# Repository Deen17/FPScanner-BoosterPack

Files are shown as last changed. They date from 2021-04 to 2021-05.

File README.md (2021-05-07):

# CCS Code for the FPScanner
For use with a GT-521FXX Fingerprint Scanner. 

This project contains library code for the fingerprint scanner, compatible with TI LaunchPad devices. To follow along with the entire design of the project, check out https://www.hackster.io/adilr3/fpscanner-boosterpack-739ad2.

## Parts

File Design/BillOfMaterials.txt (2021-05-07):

Quantity	Value	Package	Order code	Manufacturer	Manuf. Code	Availability	Price (from)	Description
-------
2   2x10 HEADERS 2x10	SAM15296-ND SAMTEC	SSW-110-23-F-D I found https://www.digikey.com/en/products/detail/SSW-110-23-F-D/SAM15296-ND/6692909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, which shows these 2x10 headers are in stock. Should only need 2 of these)
-------

Quantity	Value	Package	Order code	Manufacturer	Manuf. Code	Availability	Price (from)	Description
2	10k	R0805	53W8524	PANASONIC	ERJ6GEYJ103V	50390	0.021	PANASONIC - ERJ6GEYJ103V - Surface Mount Chip Resistor, Thick Film, AEC-Q200 ERJ Series, 10 kohm, 125 mW, 5%, 150 V RoHS Compliant: Yes
1	20k	R0805	65J1661	VISHAY	CRCW080520K0FKEB	6392	0.014	VISHAY - CRCW080520K0FKEB - SMD Chip Resistor, 20 kohm, ± 1%, 125 mW, 0805 [2012 Metric], Thick Film, General Purpose
2		1X04_1MM_RA	87R0314	JST (JAPAN SOLDERLESS TERMINALS)	SM04B-SRSS-TB(LF)(SN)	8511	0.347	JST (JAPAN SOLDERLESS TERMINALS) - SM04B-SRSS-TB(LF)(SN) - Pin Header, Wire-to-Board, 1 mm, 1 Rows, 4 Contacts, Surface Mount, SH Series
1	M3 Screws PRT-13227	Sparkfun	https://www.sparkfun.com/products/13227 
4	M3 Nuts

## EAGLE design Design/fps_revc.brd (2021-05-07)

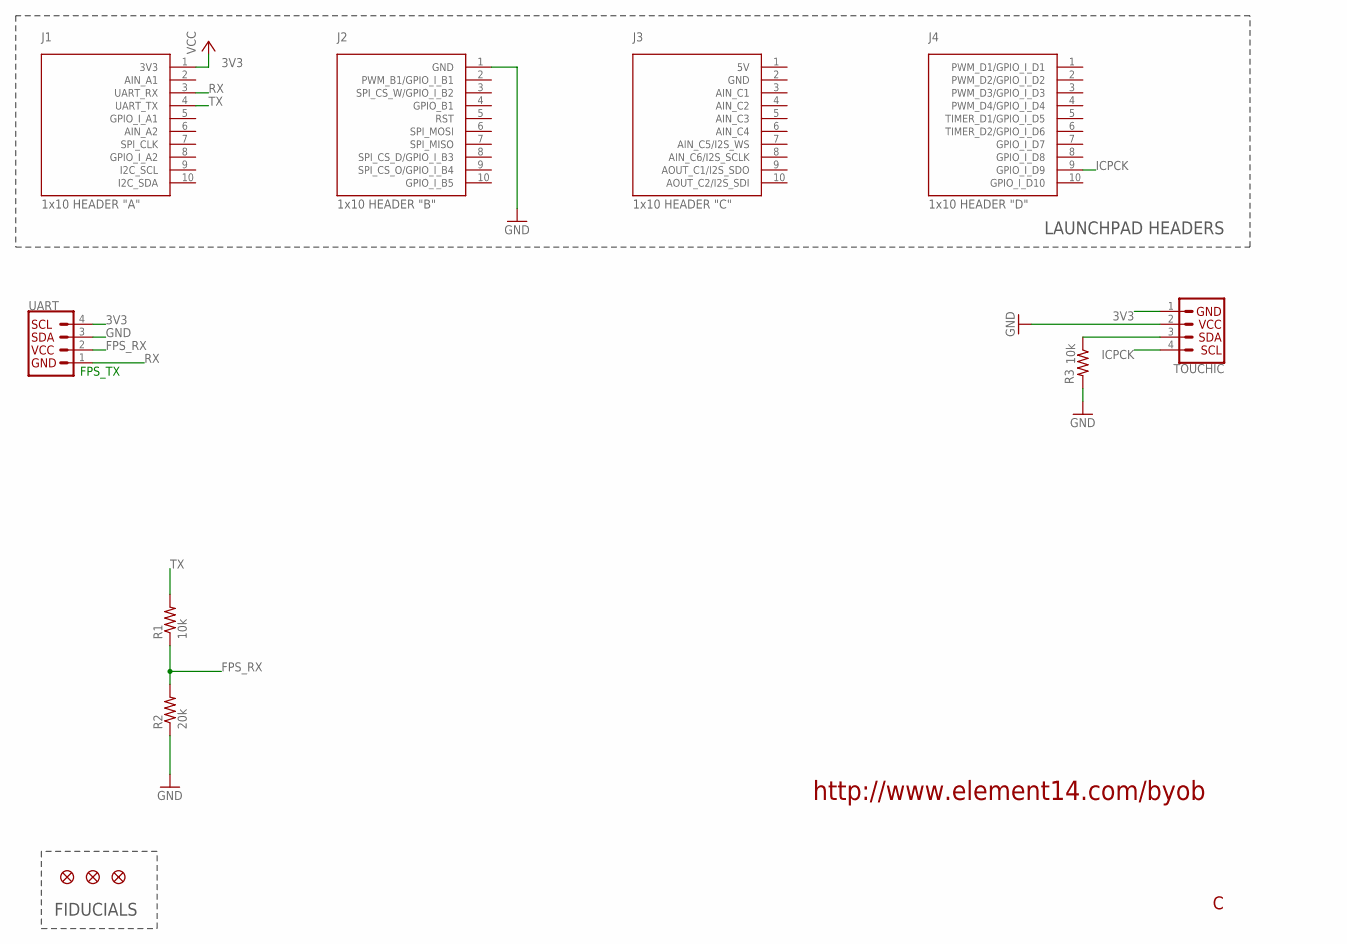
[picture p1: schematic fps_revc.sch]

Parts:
FID1, FID2, FID3: FIDUCIAL; FIDUCIAL_L10
J1: 1x10 HEADER "A"; 1X10; MPN SSW-110-23-F-D
J2: 1x10 HEADER "B"; 1X10; MPN SSW-110-23-F-D
J3: 1x10 HEADER "C"; 1X10
J4: 1x10 HEADER "D"; 1X10
R1, R3: 10k; R0805; MPN ERJ6GEYJ103V
R2: 20k; R0805; MPN CRCW080520K0FKEB
TOUCHIC: QWIIC_CONNECTORJS-1MM; 1X04_1MM_RA; MPN SM04B-SRSS-TB(LF)(SN)
UART: QWIIC_CONNECTORJS-1MM; 1X04_1MM_RA; MPN SM04B-SRSS-TB(LF)(SN)

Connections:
3V3: J1.1 (3V3), TOUCHIC.1 (GND), UART.4 (SCL)
FPS_RX: R1.1, R2.2, UART.2 (VCC)
GND: J2.1 (GND), R2.1, R3.2, TOUCHIC.2 (VCC), UART.3 (SDA)
ICPCK: J4.9 (GPIO_I_D9), TOUCHIC.4 (SCL)
unnamed: R3.1, TOUCHIC.3 (SDA)
RX: J1.3 (UART_RX), UART.1 (GND)
TX: J1.4 (UART_TX), R1.2

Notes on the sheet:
LAUNCHPAD HEADERS
FIDUCIALS
http://www.element14.com/byob
FPS_TX

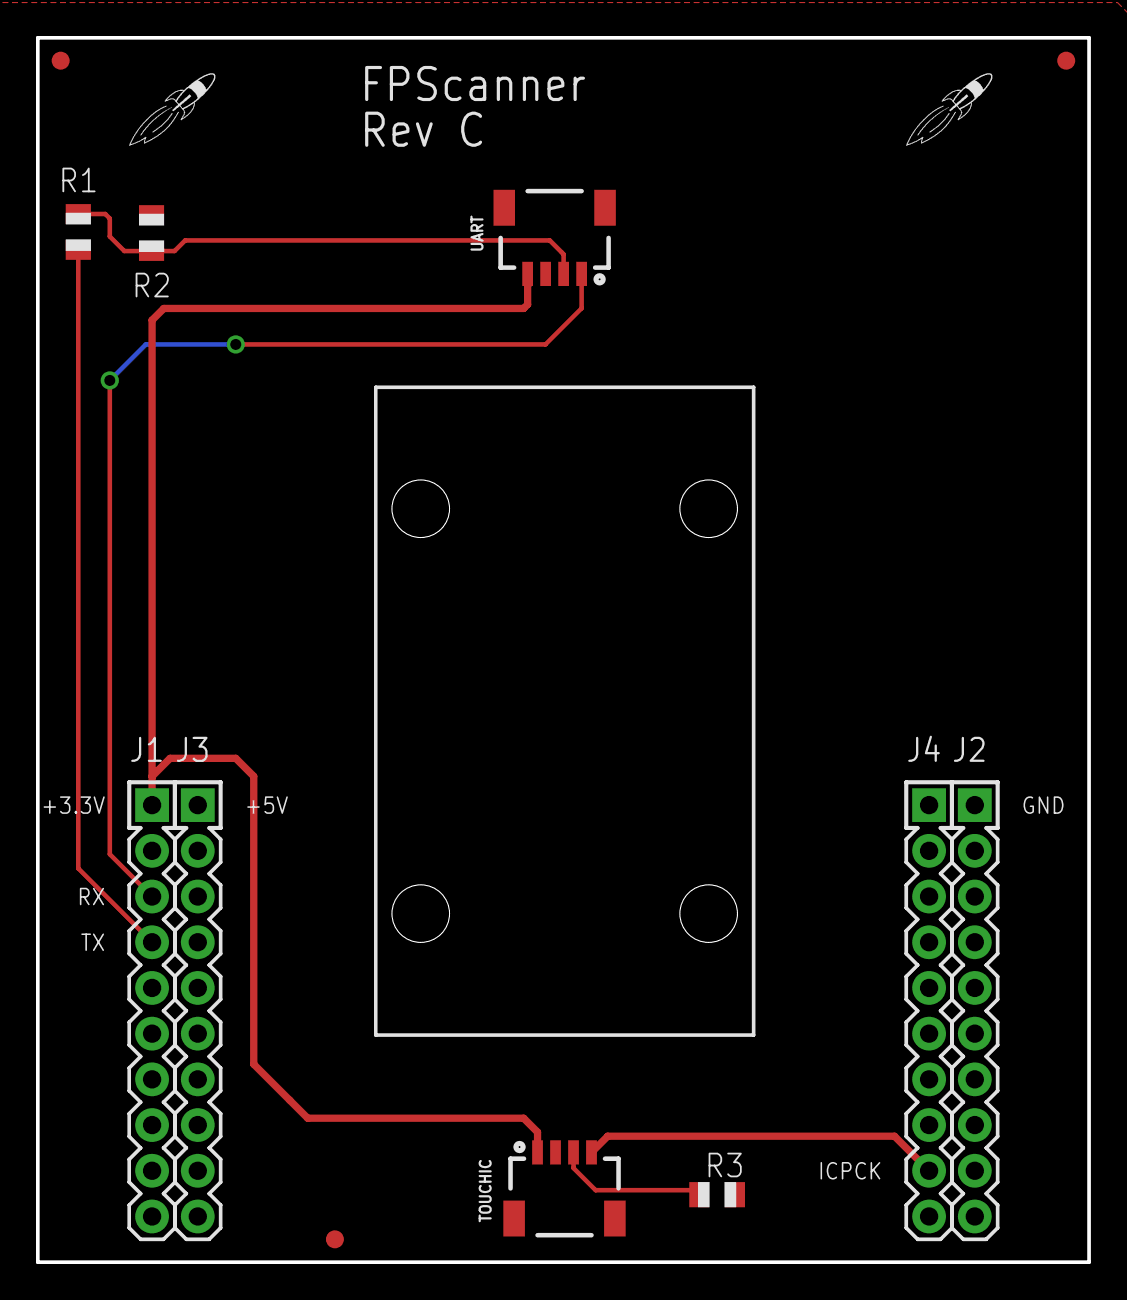
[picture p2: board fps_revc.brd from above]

Board: 2 copper layers, 58.4 x 68.0 mm, 14 parts (0 on the bottom side), 7 nets.

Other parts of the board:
U$1, U$2: LOGO-ROCKET

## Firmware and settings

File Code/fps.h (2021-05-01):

///
//
// 

#ifndef FPS_HEADER
#define FPS_HEADER

#ifndef TI_UART
#define TI_UART
#include <ti/drivers/UART.h>
#endif

#ifndef TI_DRIVERS_CONFIG
#define TI_DRIVERS_CONFIG
#include "ti_drivers_config.h"
#endif

#ifndef TI_GPIO
#define TI_GPIO
#include <ti/drivers/GPIO.h>
#endif

#define COMMAND_PACKET_SIZE 12
#define RESPONSE_PACKET_SIZE 12

typedef unsigned char byte;
typedef unsigned short word;
typedef unsigned long dword;

static byte command_start_code1 = 0x55;
static byte command_start_code2 = 0xaa;
static byte data_start_code1 = 0x5a;
static byte data_start_code2 = 0xa5;
static byte device_id1 = 0x01; // lsB; together, deviceID is 0x0001. the fingerprintscanner is little endian
static byte device_id2 = 0x00; // msB

// Command Codes
enum Command_Code
{
    OPEN = 0x01,
    CLOSE = 0x02,
    USB_INTERNAL_CHECK = 0X03,
    CHANGE_BAUDRATE = 0X04,
    CMOS_LED = 0X12,
    GET_ENROLL_COUNT = 0X20,
    CHECK_ENROLLED = 0X21,
    ENROLL_START = 0X22,
    ENROLL1 = 0X23,
    ENROLL2 = 0X24,
    ENROLL3 = 0X25,
    IS_PRESS_FINGER = 0X26,
    DELETE_ID = 0X40,
    DELETE_ALL = 0X41,
    VERIFY = 0X50,
    IDENTIFY = 0X51,
    VERIFY_TEMPLATE = 0X52,
    IDENTIFY_TEMPLATE = 0X53,
    CAPTURE_FINGER = 0X60,
    MAKE_TEMPLATE = 0X61,
    GET_IMAGE = 0X62,
    GET_RAW_IMAGE = 0X63,
    GET_TEMPLATE = 0X70,
    SET_TEMPLATE = 0X71,
    GET_DATABASE_START = 0X72,
    GET_DATABASE_END = 0X73,
    SET_SECURITY_LEVEL = 0XF0,
    GET_SECURITY_LEVEL = 0XF1,
    IDENTIFY_TEMPLATE2 = 0XF4,
    ENTER_STANDBY_MODE = 0XF9,
    ACK = 0X30,
    NACK = 0X31
} Command;

enum ERROR_CODES
{
    NACK_TIMEOUT = 0X1001,
    NACK_INVALID_BAUDRATE = 0X1002,
    NACK_INVALID_POS = 0X1003,
    NACK_IS_NOT_USED = 0X1004,
    NACK_IS_ALREADY_USED = 0X1005,
    NACK_COMM_ERR = 0X1006,
    NACK_VERIFY_FAILED = 0X1007,
    NACK_IDENTIFY_FAILED = 0X1008,
    NACK_DB_IS_FULL = 0X1009,
    NACK_DB_IS_EMPTY = 0X100A,
    NACK_TURN_ERR = 0X100B,
    NACK_BAD_FINGER = 0X100C,
    NACK_ENROLL_FAILED = 0X100D,
    NACK_IS_NOT_SUPPORTED = 0X100E,
    NACK_DEV_ERR = 0X100F,
    NACK_CAPTURE_CANCELED = 0X1010,
    NACK_INVALID_PARAM = 0X1011,
    NACK_FINGER_IS_NOT_PRESSED = 0X1012,
    INVALID = 0XFFFF
} Error_Code;

// // Response Codes
// enum Response_Code {
//     ACK  = 0x30,
//     NACK = 0x31
// } Response;

// Packet Structures

// Command Packet
typedef struct CMD_PKT
{
    dword parameter;
    word command;
} CommandPacket;

CommandPacket new_command_packet(word command, dword parameter);
word cmd_checksum(CommandPacket *self);
CommandPacket open_cmd(dword parameter);
CommandPacket close_cmd();
CommandPacket check_usb_cmd();
CommandPacket led_cmd(dword parameter);
CommandPacket led_on_cmd();
CommandPacket led_off_cmd();
CommandPacket change_baud_cmd(dword parameter);
CommandPacket get_enroll_count_cmd();
CommandPacket check_enrollment_cmd(dword id);
CommandPacket start_enrollment_cmd(dword id);
CommandPacket enroll1_cmd();
CommandPacket enroll2_cmd();
CommandPacket enroll3_cmd();
CommandPacket check_finger_pressed_cmd();
CommandPacket delete_one_fingerprint_cmd(dword id);
CommandPacket delete_all_cmd();
CommandPacket verify_cmd(dword id);
CommandPacket identify_cmd();
CommandPacket capture_finger_cmd(dword quality);
CommandPacket get_fingerprint_img_cmd();
CommandPacket set_security_level_cmd(dword level);
CommandPacket get_security_level_cmd();
CommandPacket enter_standby_cmd();


byte* command_packet_payload(CommandPacket *self);


// Response Packet

typedef struct RES_PKT
{
    word start_code;
    word device_id;
    dword parameter;
    word response;
    word checksum;
} ResponsePacket;

ResponsePacket new_response_packet(byte* buf);
int isAck(ResponsePacket *res);
int expected_checksum(dword parameter, word response);

// Data Packets

//typedef struct DATA_PACKET
//{
//    byte start1;
//    byte start2;
//    word dev_id;
//    byte *data;
//    word checksum;
//    unsigned int size;
//} DataPacket;

//DataPacket data_packet(byte *buf, int size);
//word data_checksum(DataPacket *self);


/*
 * Struct: devinfo
 * ---------------
 * The FPS returns this data after sending an OPEN
 * command with a nonzero parameter.
 */
struct devinfo{
    word data_start_code;
    word device_code;
    dword firmwareVersion;
    dword isoAreaMaxSize;
    byte deviceSerialNumber[16];
    word checksum;
};

struct devinfo devinfo_frombytes(byte* arr);

typedef struct ResponseParam{
    dword parameter;
    int res;
} result;

// FPS UART commands
int fps_open_info(UART_Handle handle);
int fps_open(UART_Handle handle);
int fps_close(UART_Handle handle);
int _fps_led(UART_Handle handle, dword i);
int fps_led_on(UART_Handle handle);
int fps_led_off(UART_Handle handle);
int fps_check_usb(UART_Handle handle);
int fps_enroll_count(UART_Handle handle);
result fps_check_enrolled(UART_Handle handle, dword id);
result fps_enroll_start(UART_Handle handle, dword id);
result fps_enrolln(UART_Handle handle, int n);
int fps_is_finger_pressed_uart(UART_Handle handle);
result fps_delete_id(UART_Handle handle, dword id);
result fps_delete_all(UART_Handle handle);
result fps_verify(UART_Handle handle, dword id);
result fps_identify(UART_Handle handle);
result fps_capture_finger(UART_Handle handle, dword quality);
int fps_standby(UART_Handle); // to wake up, send a 0x00 first and wait 20ms (what?)
result _req_res(UART_Handle handle, word command, dword id);
int icpck();
#endif

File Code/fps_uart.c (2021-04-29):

#ifndef FPS_UART
#define FPS_UART

#include "fps.h"

#ifndef STDLIB
#define STDLIB
#include <stdlib.h>
#endif

/*
 * fps_uart.c
 *
 *  Created on: Mar 16, 2021
 *      Author: Deen17
 */


//int _req_res(UART_Handle handle, word command, dword id){
//    CommandPacket pkt = new_command_packet(command,id);
//    byte* buf = command_packet_payload(&pkt);
//    int32_t status = UART_write(handle, buf, RESPONSE_PACKET_SIZE);
//    if (status != COMMAND_PACKET_SIZE) {
//        free(buf);
//
//        return -1;
//    }
//    status = UART_read(handle, buf, RESPONSE_PACKET_SIZE);
//    if (status == RESPONSE_PACKET_SIZE){
//        ResponsePacket res = new_response_packet(buf);
//        if (res.response == ACK){
//            return 0;
//        }
//        if(res.response == NACK) return res.response;
//        return -1;
//    }
//    free(buf);
//    return -1;
//}


/*
 * Function: fps_open_info
 * -------------
 * A dev function that finds the devinfo data from the
 * fingerprint scanner, in addition to initializing communication.
 *
 * handle: a UART Handle according to the TI UART.h
 *
 * returns: 0 if successful, or nonzero if unsuccessful
 */
int fps_open_info(UART_Handle handle){
    CommandPacket pkt = open_cmd(1);
    byte* buf = command_packet_payload(&pkt);
    int32_t status = UART_write(handle, buf, COMMAND_PACKET_SIZE);
    if (status != COMMAND_PACKET_SIZE){
        free(buf);
        return -1;
    }
    status = UART_read(handle, buf, RESPONSE_PACKET_SIZE);
    if (status == RESPONSE_PACKET_SIZE){
        ResponsePacket res = new_response_packet(buf);
        if (res.checksum == expected_checksum(0, ACK) ){

            byte* data = (byte*)malloc(sizeof(byte) * 30);
            status = UART_read(handle, data, 30);
            struct devinfo info = devinfo_frombytes(data);

            return 0;
        }
        return -1;
    }
    free(buf);
    return -1;
}

/*
 * Function: fps_open
 * -------------
 * Initializes communication to the fingerprint scanner.
 *
 * handle: a UART Handle according to the TI UART.h
 *
 * returns: 0 if successful, or nonzero if unsuccessful
 */
int fps_open(UART_Handle handle){
    CommandPacket pkt = open_cmd(0);
    byte* buf = command_packet_payload(&pkt);
    int32_t status = UART_write(handle, buf, COMMAND_PACKET_SIZE);
    if (status != COMMAND_PACKET_SIZE){
        free(buf);
        return -1;
    }
    status = UART_read(handle, buf, RESPONSE_PACKET_SIZE);
    if (status == RESPONSE_PACKET_SIZE){
        ResponsePacket res = new_response_packet(buf);
        if (res.checksum == expected_checksum(0, ACK) ){
            return 0;
        }
        return -1;
    }
    free(buf);
    return -1;
}

/*
 * Function: fps_close
 * -------------
 * Initializes communication to the fingerprint scanner.
 *
 * handle: a UART Handle according to the TI UART.h
 *
 * returns: 0 if successful, or nonzero if unsuccessful
 */
int fps_close(UART_Handle handle){
    CommandPacket pkt = close_cmd(0);
    byte* buf = command_packet_payload(&pkt);
    int32_t status = UART_write(handle, buf, COMMAND_PACKET_SIZE);
    if (status != COMMAND_PACKET_SIZE){
        free(buf);
        return -1;
    }
    status = UART_read(handle, buf, RESPONSE_PACKET_SIZE);
    if(status == RESPONSE_PACKET_SIZE){
        ResponsePacket res = new_response_packet(buf);
        if (res.checksum == expected_checksum(0, ACK)){
            return 0;
        }
        return -1;
    }
    free(buf);
    return -1;
}

int _fps_led(UART_Handle handle, dword i){
    CommandPacket pkt = led_cmd(i);
    byte* buf = command_packet_payload(&pkt);
    int32_t status = UART_write(handle, buf, COMMAND_PACKET_SIZE);
    if (status != COMMAND_PACKET_SIZE){
        free(buf);
        return -1;
    }
    status = UART_read(handle, buf, RESPONSE_PACKET_SIZE);
    if (status == RESPONSE_PACKET_SIZE){
        ResponsePacket res = new_response_packet(buf);
        if (res.checksum == expected_checksum(0, ACK)){
            return 0;
        }
        return -1;
    }
    free(buf);
    return -1;
}

/*
 * Function: fps_led_on
 * -------------
 * Turns the LED backlight on.
 *
 * handle: a UART Handle according to the TI UART.h
 *
 * returns: 0 if successful, or nonzero if unsuccessful
 */
int fps_led_on(UART_Handle handle){
    return _fps_led(handle, 1);
}

/*
 * Function: fps_led_off
 * -------------
 * Turns the LED backlight off.
 *
 * handle: a UART Handle according to the TI UART.h
 *
 * returns: 0 if successful, or nonzero if unsuccessful
 */
int fps_led_off(UART_Handle handle){
    return _fps_led(handle, 0);
}

int fps_check_usb(UART_Handle handle){
    CommandPacket pkt = check_usb_cmd();
    byte* buf = command_packet_payload(&pkt);
    int32_t status = UART_write(handle, buf, RESPONSE_PACKET_SIZE);
    if (status != COMMAND_PACKET_SIZE) {
        free(buf);
        return -1;
    }
    status = UART_read(handle, buf, RESPONSE_PACKET_SIZE);
    if (status == RESPONSE_PACKET_SIZE){
        ResponsePacket res = new_response_packet(buf);
        if (res.checksum == expected_checksum(0x55, ACK)){
            return 0;
        }
        return -1;
    }
    free(buf);
    return -1;
}

/*
 * Returns the number of enrolled fingerprints, or -1 if an error occurred.
 */
int fps_enroll_count(UART_Handle handle){
    CommandPacket pkt = new_command_packet(GET_ENROLL_COUNT, 0);
    byte* buf = command_packet_payload(&pkt);
    int32_t status = UART_write(handle, buf, RESPONSE_PACKET_SIZE);
    if (status != COMMAND_PACKET_SIZE) {
        free(buf);
        return -1;
    }
    status = UART_read(handle, buf, RESPONSE_PACKET_SIZE);
    if (status == RESPONSE_PACKET_SIZE){
        ResponsePacket res = new_response_packet(buf);
        if (res.response == ACK){
            return res.parameter;
        }
        return -1;
    }
    free(buf);
    return -1;
}

result _req_res(UART_Handle handle, word command, dword id){
    CommandPacket pkt = new_command_packet(command,id);
    byte* buf = command_packet_payload(&pkt);
    result r;
    int32_t status = UART_write(handle, buf, RESPONSE_PACKET_SIZE);
    if (status != COMMAND_PACKET_SIZE) {
        free(buf);
        r = (result) {0,-1};
        return r;
    }
    status = UART_read(handle, buf, RESPONSE_PACKET_SIZE);
    if (status == RESPONSE_PACKET_SIZE){
        ResponsePacket res = new_response_packet(buf);
        if (res.response == ACK){
            r = (result) {res.parameter, 0};
            return r;
        }
        if(res.response == NACK) return (result) {res.parameter,-1};
        return (result) {0,-2};
    }
    free(buf);
    return (result) {0,-3};
}

result fps_check_enrolled(UART_Handle handle, dword id){
    return _req_res(handle, CHECK_ENROLLED, id);
}

result fps_enroll_start(UART_Handle handle, dword id){
    return _req_res(handle, ENROLL_START, id);
}
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

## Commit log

2021-03-17 Need to figure out how to communicate with UART via pins, not via USB
2021-03-17 fixed expected_checksum, changed sleep lengths, prob need to add a clock
    [uartecho.c]
2021-03-19 1st working set of code for fingerprint scanner
    fps.h: devinfo struct, data start code
    fps_cmd.c: corrected && to & operator
    for checksum & payload func
    fps_uart/c: fps_check_usb,
    fps_open_info
    [fps.h, fps_uart.c, uartecho.c]
2021-04-04 little more uart work
2021-04-29 various bugfixes, testing enrollment/identification
    [fps.h, fps_run.c, fps_uart.c]
2021-05-01 clarity in enrollment success vs verification success in LEDs
2021-05-02 revert to working code
    [fps_run.c]
2021-05-07 restructuring, includes design files
    [fps_revc.brd, fps_revc.sch]

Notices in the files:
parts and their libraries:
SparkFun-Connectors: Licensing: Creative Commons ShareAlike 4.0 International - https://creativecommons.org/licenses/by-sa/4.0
